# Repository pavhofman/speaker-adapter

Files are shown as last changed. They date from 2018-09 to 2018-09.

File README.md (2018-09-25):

# Adapter for Measuring Amplifier Speaker Outputs

## Overview
* Designed for soundcard balanced inputs
* Designed to fit [headless audio measurement workstation](https://github.com/pavhofman/measurement-station) but will work with any soundcard
* Can be switched to unbalanced mode (single-ended SE)
* Designed to fit FS Futro >=S450 case (inexpensive on ebay)

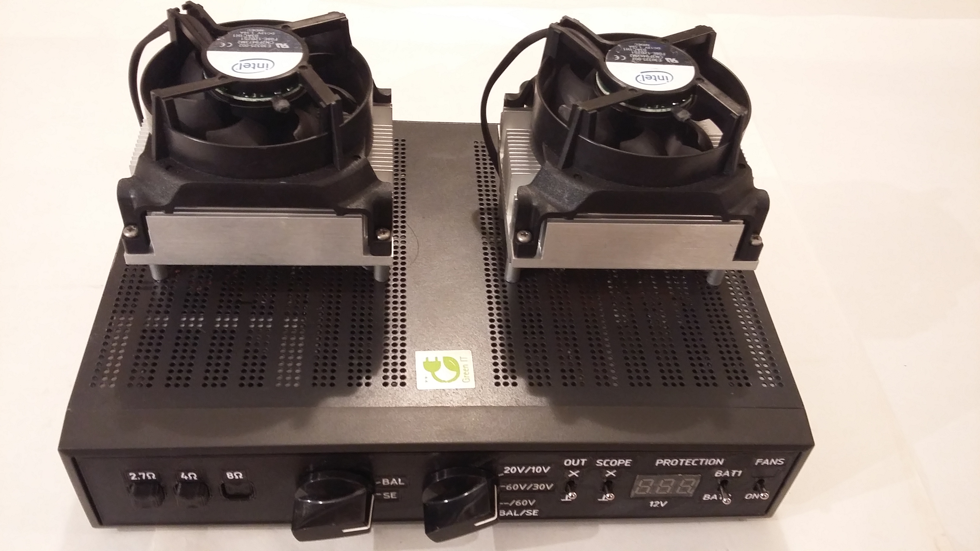
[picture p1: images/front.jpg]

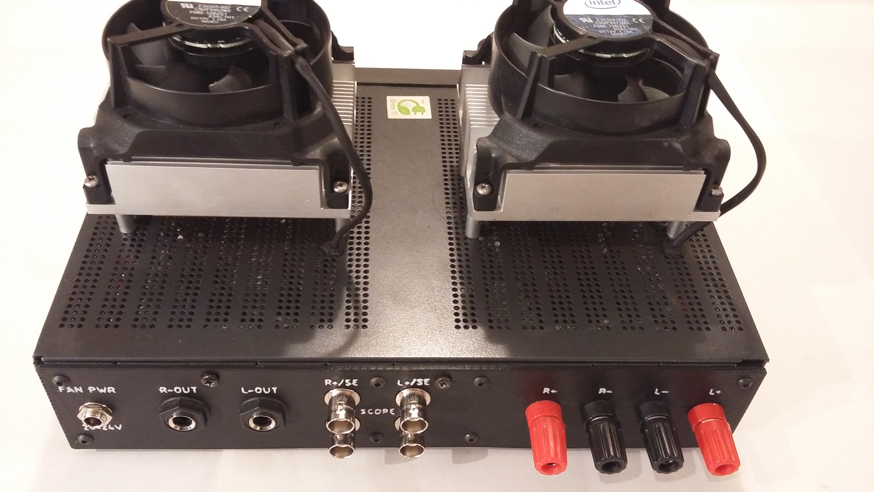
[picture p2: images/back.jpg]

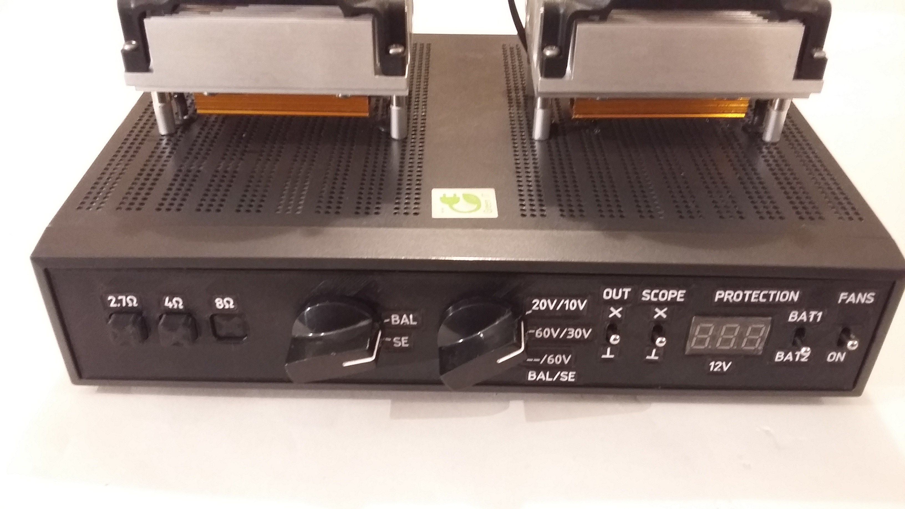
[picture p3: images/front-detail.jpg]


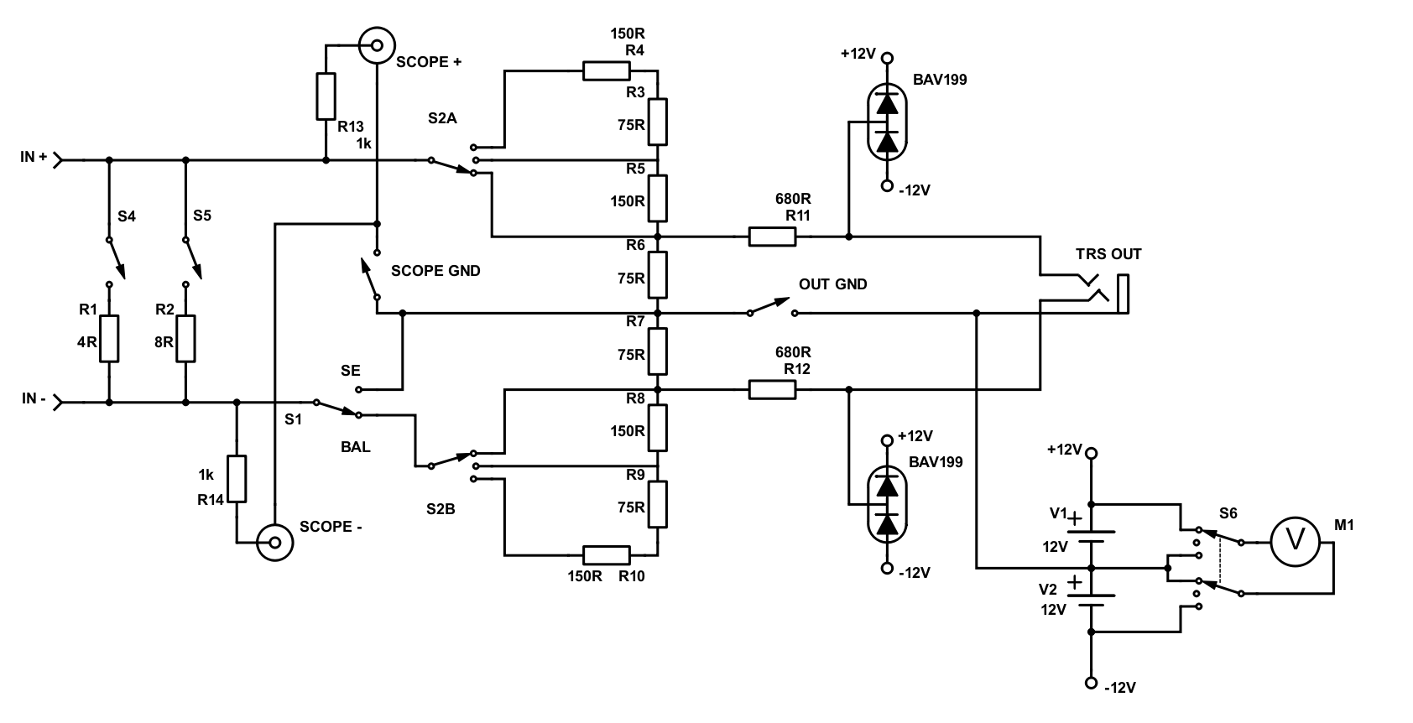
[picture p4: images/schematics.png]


## Speaker Load
* Load resistors - combination of 4R and 8R 100W resistors (ebay)
* Old/legacy CPU heatsinks with fans
* Fans powered by the measurement PC

## Ranges
* Ranges (voltages for ESI Juli):
  1. 1:1 (20Vmax balanced / 10Vmax SE) - divider 2 x 75R
  2. 1:3 (60Vmax balanced / 30Vmax SE) - divider 2 x (75R + 150R)
  3. 1:6 (120Vmax balanced - not supported/60Vmax SE) - divider 2 x (75R + 375R)
* Divider resistors 2W: 20V at (75R + 75R) -> 1.3W per each resistor
* Ground lift for balanced outputs

## Oscilloscope Output
* Each input line is connected to individual BNC connector for oscilloscope
* Ground lift for scope BNCs

## Soundcard Inputs Protection
* Serial output resistors 680R
* Soundcard hot/cold input protection by two internal voltage sources (2 x 2pcs A23 batteries)
* Protection diodes - dual low-leakage diodes BAV199
* Both sets of protection batteries checked by built-in voltmeter prior to measuring.

Scope screenshot of protection limiter kicking in for hot and cold lines of one output:



The adapter in action:

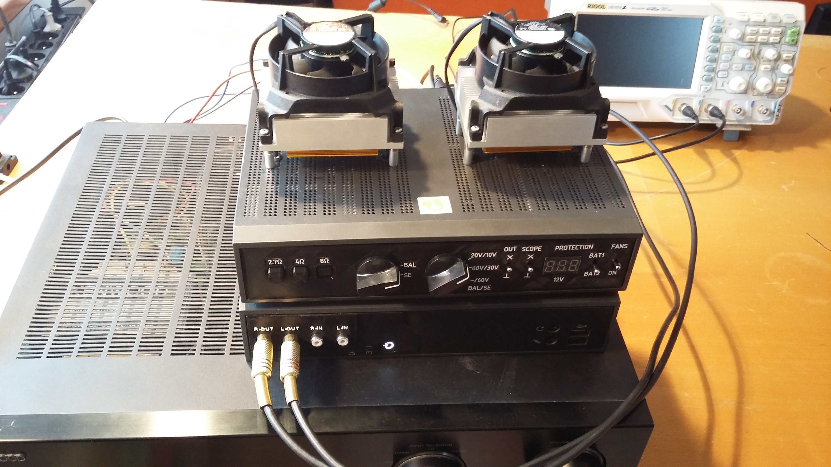
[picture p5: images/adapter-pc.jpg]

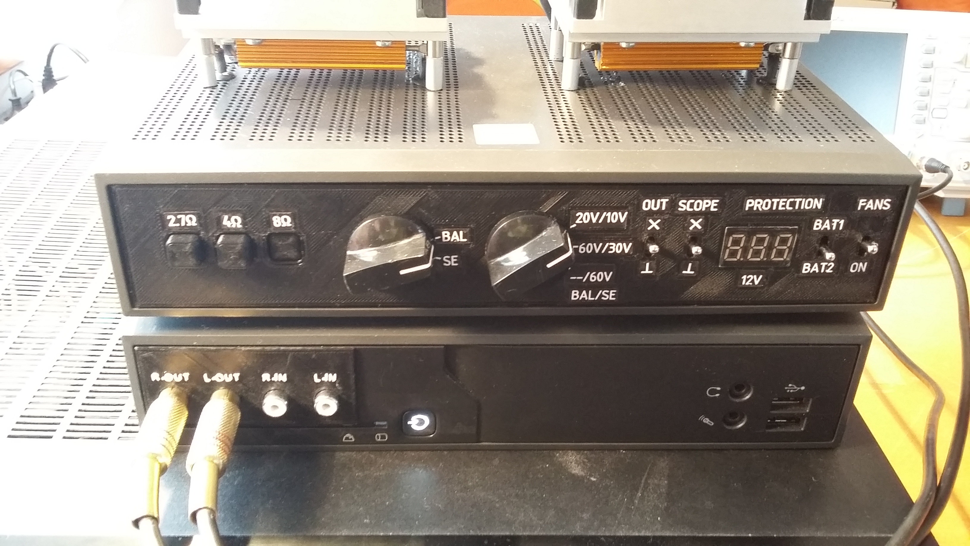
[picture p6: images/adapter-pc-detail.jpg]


## Construction
* Wired, no PCB
* SMD protection diodes soldered to small universal PCBs placed directly onto TRS sockets

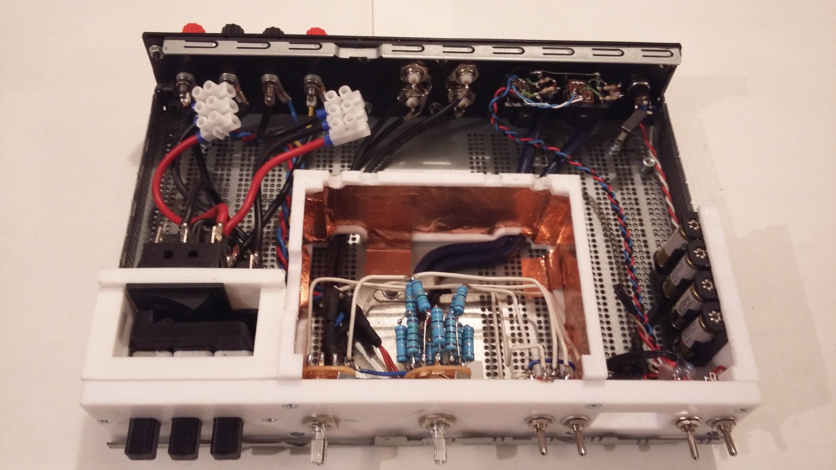
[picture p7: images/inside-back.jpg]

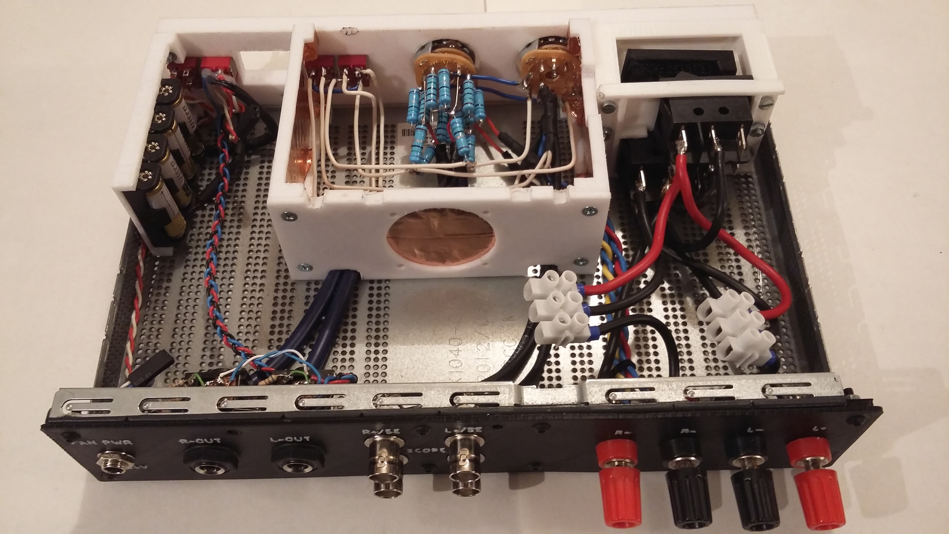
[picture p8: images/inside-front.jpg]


## Load-Resistors Switch
* 3D-printed, designed for regular 32mm rocker switches
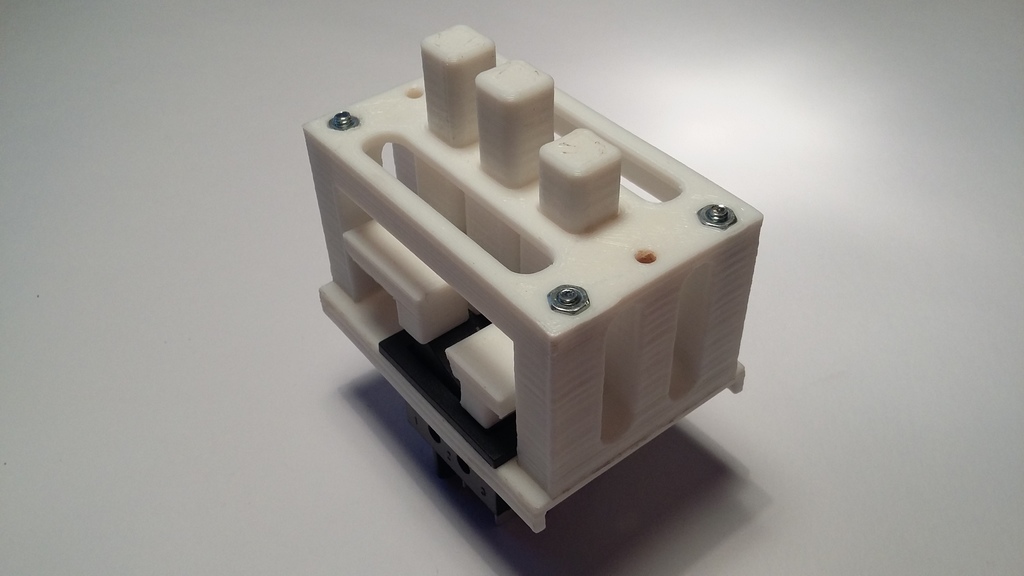
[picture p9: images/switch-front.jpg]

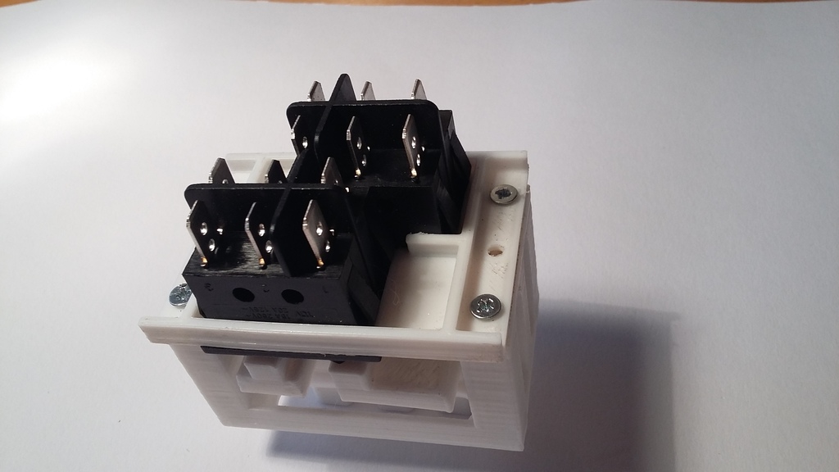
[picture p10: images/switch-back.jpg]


Position 2.7ohm - both resistors paralelly
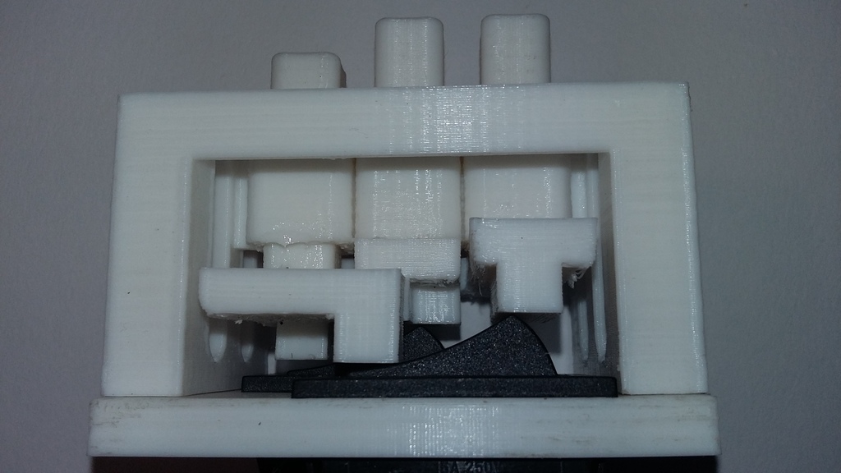
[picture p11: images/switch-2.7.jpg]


Position 4ohm
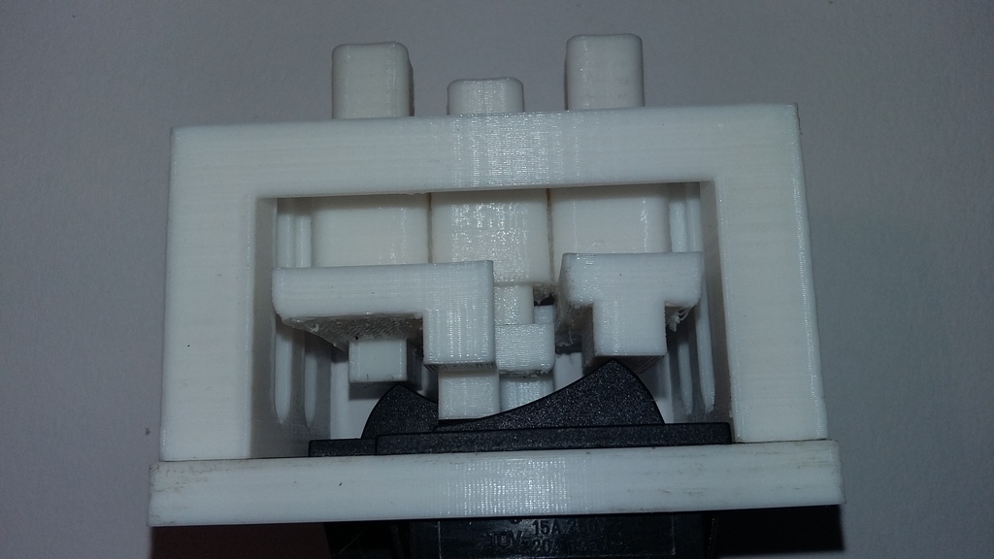
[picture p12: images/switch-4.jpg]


Position 8ohm
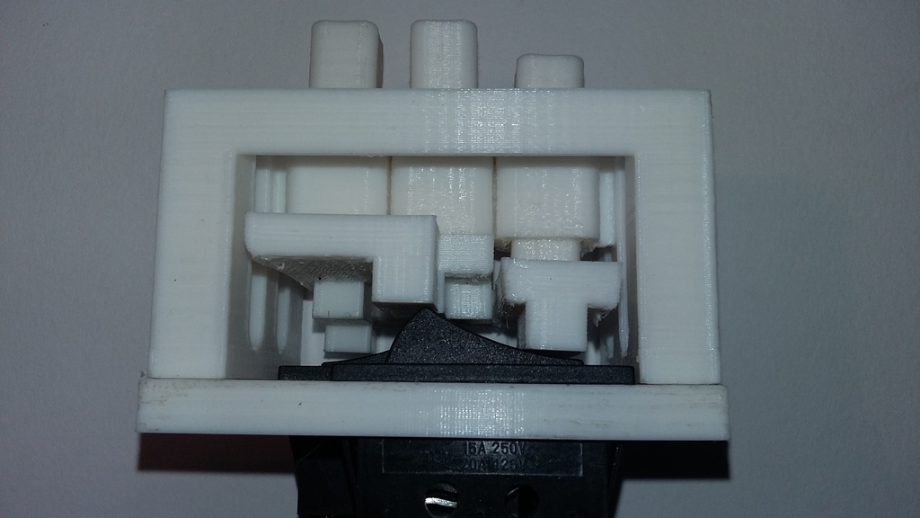
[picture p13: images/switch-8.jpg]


## Measurements
For comparison ESI Juli in virtual balanced inputs mode with L+R jacks shorted

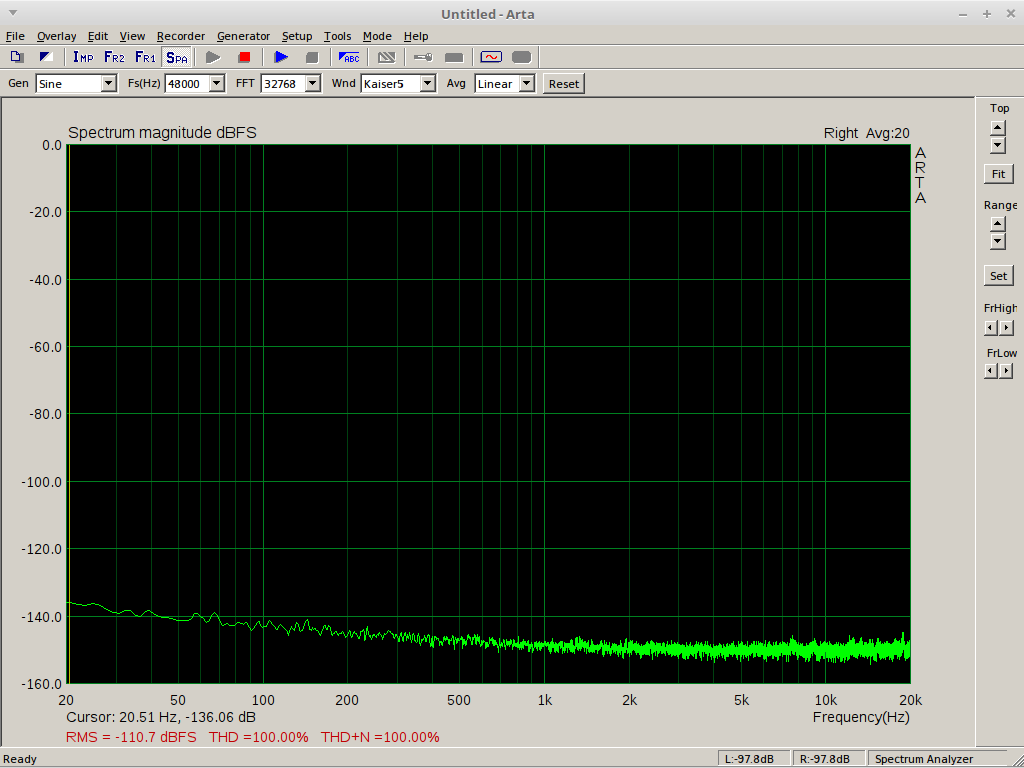
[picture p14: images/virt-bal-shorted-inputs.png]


Connected adapter, no input signal, virtual balanced inputs. Notice only minor increase in 50Hz noise, overall noise level unchanged.

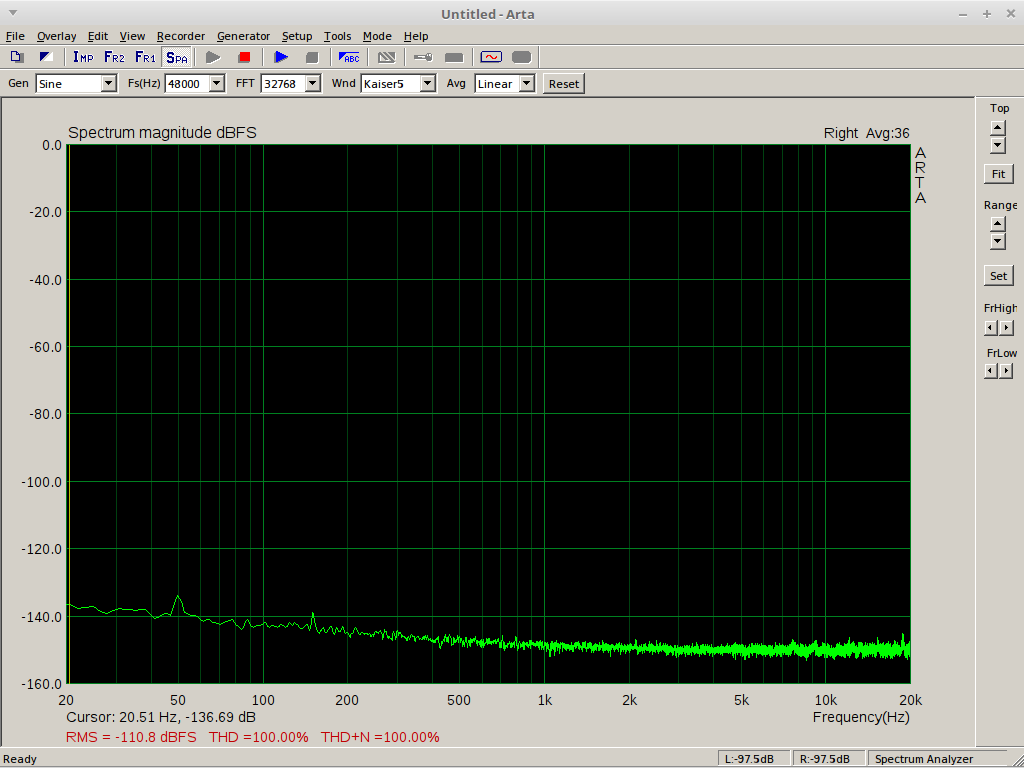
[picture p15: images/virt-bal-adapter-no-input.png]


Connected adapter, no input signal, native balanced inputs of ESI.
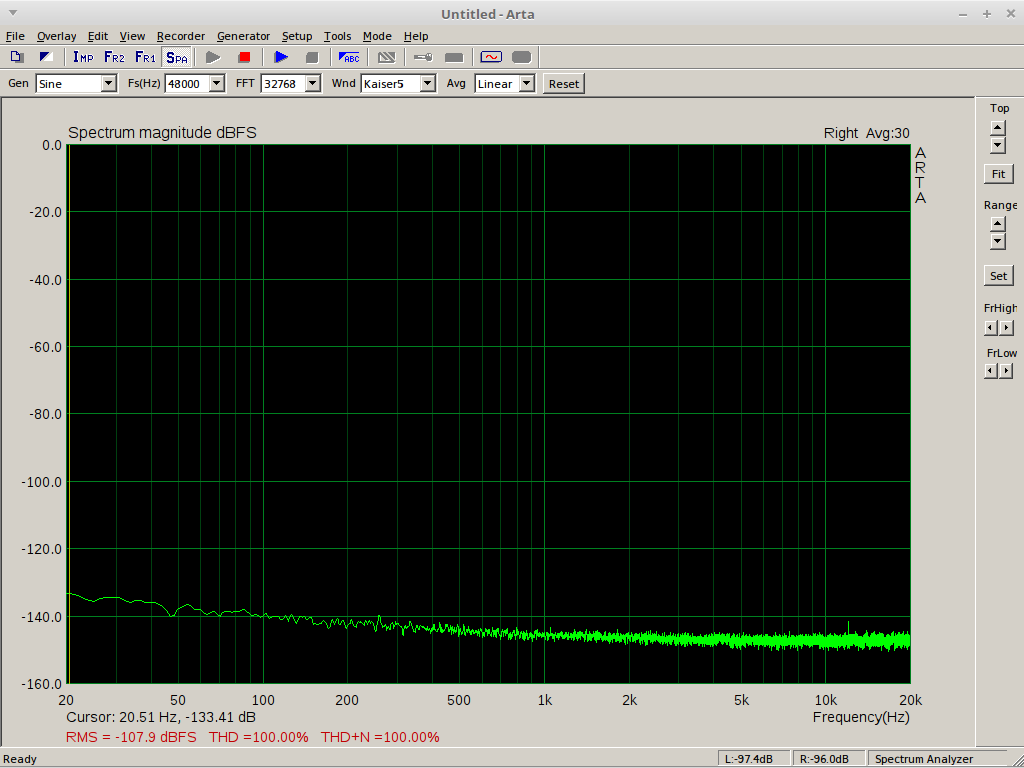
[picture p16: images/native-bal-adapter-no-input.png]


## Git repository
* All Fusion 360 backup files, STLs, front panel text image

## Conclusion
The measurements show the adapter does not bring any increase in noise of the measurement setup.

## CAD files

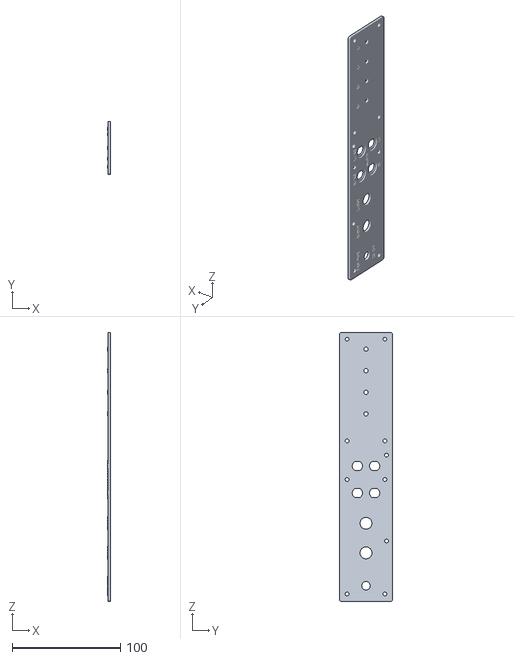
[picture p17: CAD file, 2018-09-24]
models/back_panels/Back_panel.stl
2.50 x 49.0 x 249.0

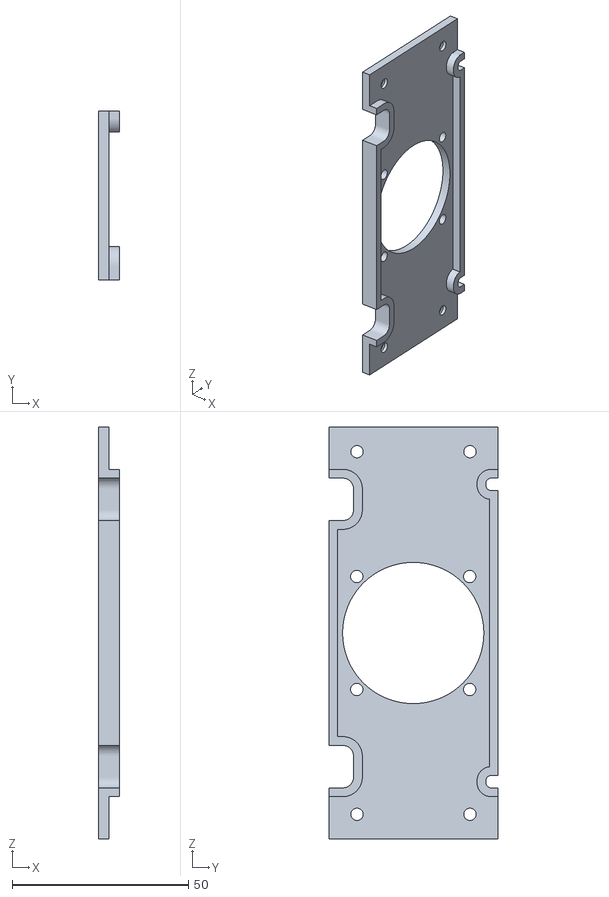
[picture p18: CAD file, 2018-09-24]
models/front_panels/BackShield.stl
6.00 x 48.0 x 116.8

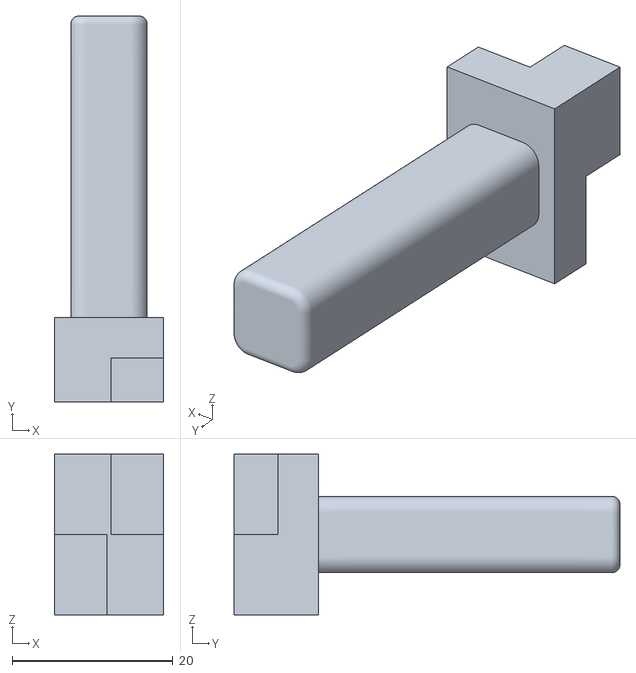
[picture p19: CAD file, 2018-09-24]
models/pushbuttons/CenterButton.stl
13.5 x 48.0 x 20.0

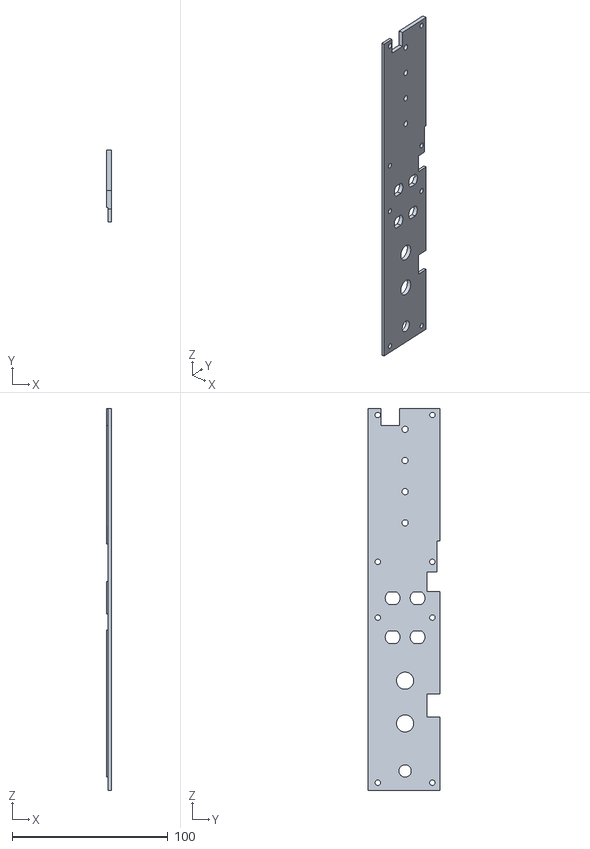
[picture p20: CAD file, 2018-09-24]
models/back_panels/Inside_Back_Panel.stl
3.00 x 46.4 x 245.0

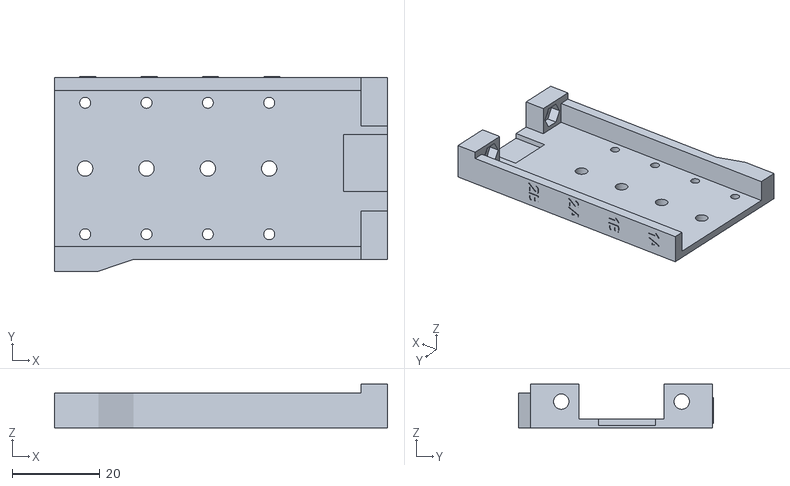
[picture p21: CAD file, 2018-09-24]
models/front_panels/BatteryPlate.stl
76.0 x 44.4 x 10.0

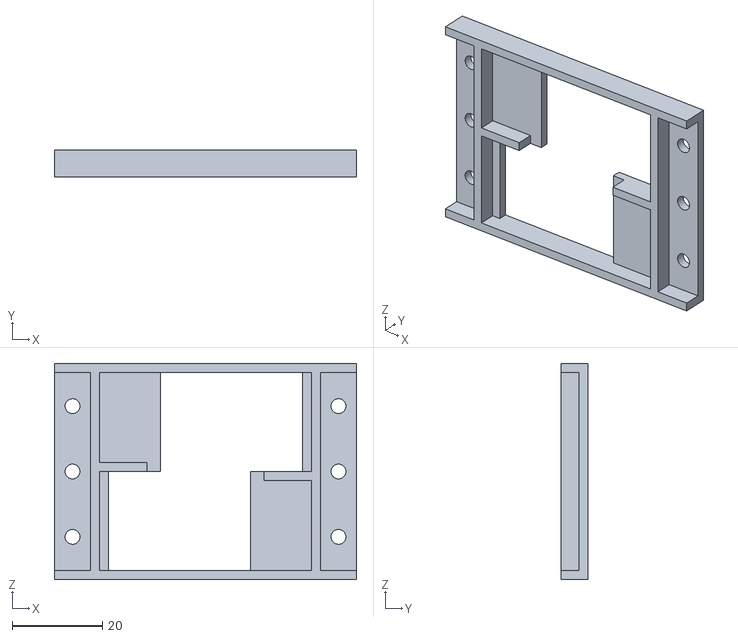
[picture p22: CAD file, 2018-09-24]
models/pushbuttons/SwitchHolderPlate.stl
67.0 x 6.00 x 48.0

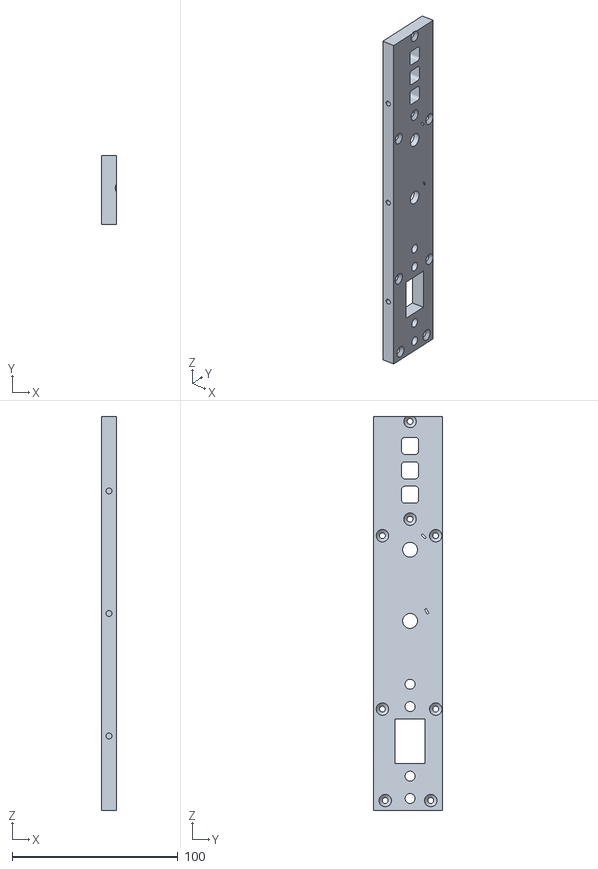
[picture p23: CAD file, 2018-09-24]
models/front_panels/HolderPanel.stl
9.00 x 41.5 x 238.0

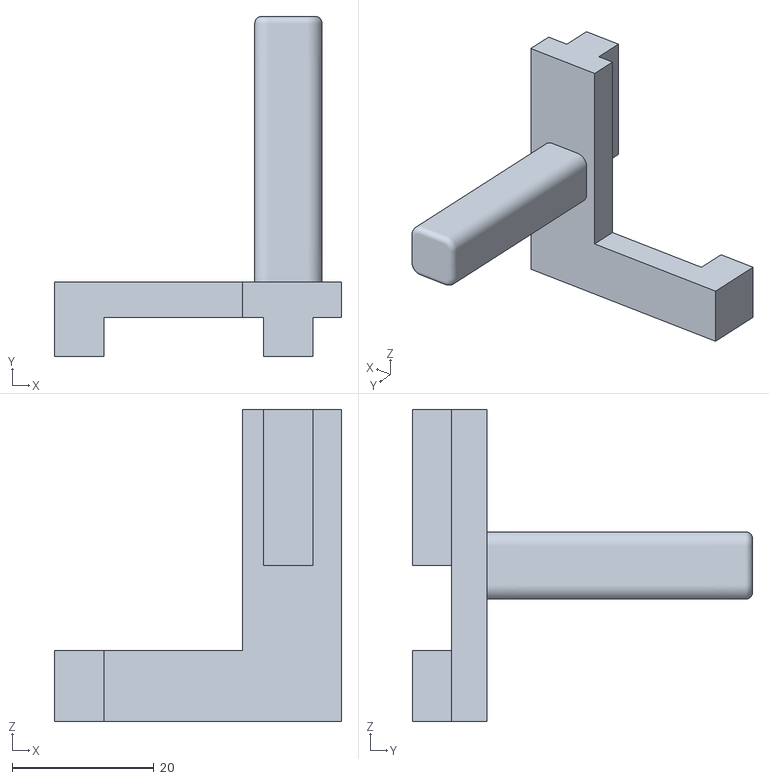
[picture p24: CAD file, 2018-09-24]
models/pushbuttons/RightButton.stl
40.5 x 48.0 x 44.0

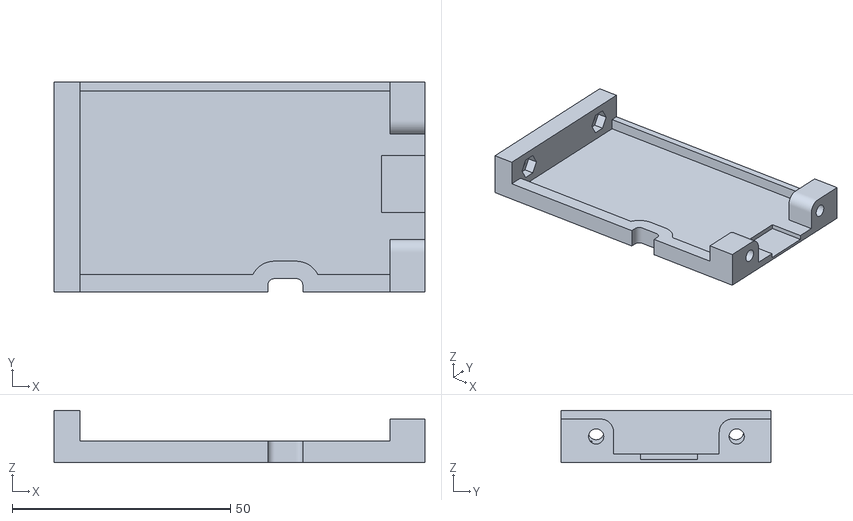
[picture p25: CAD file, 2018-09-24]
models/front_panels/RightShield.stl
85.0 x 48.0 x 12.0

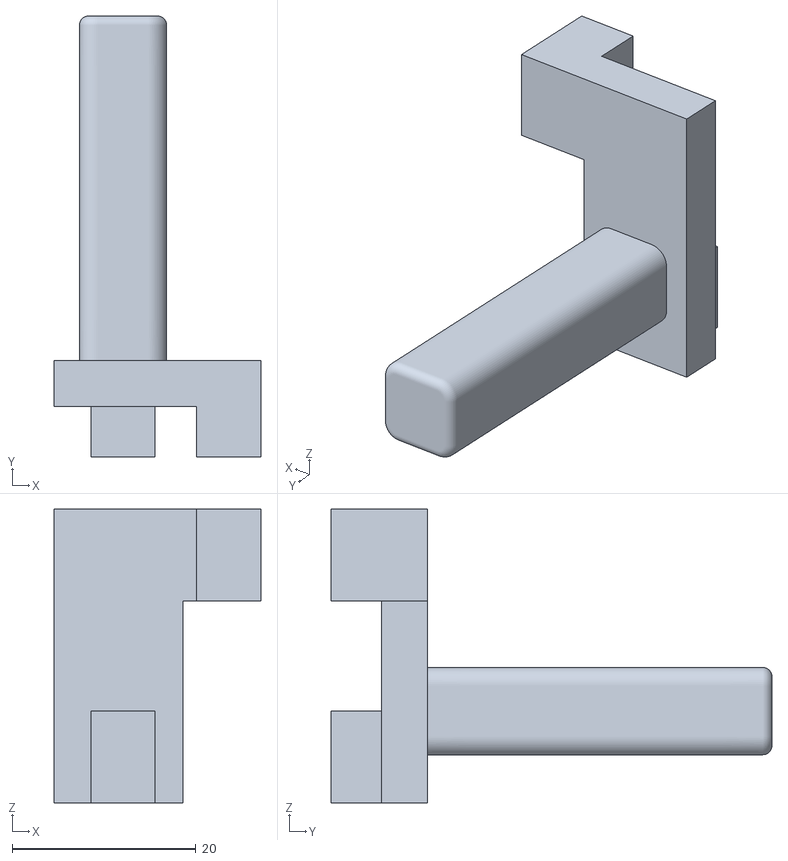
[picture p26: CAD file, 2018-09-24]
models/pushbuttons/LeftButton.stl
22.5 x 48.0 x 32.0

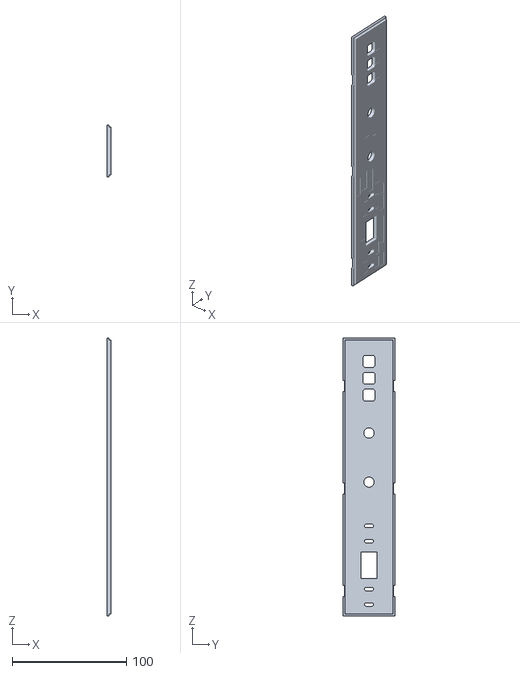
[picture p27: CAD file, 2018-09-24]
models/front_panels/FrontPanel_no_text.stl
3.30 x 45.5 x 243.5

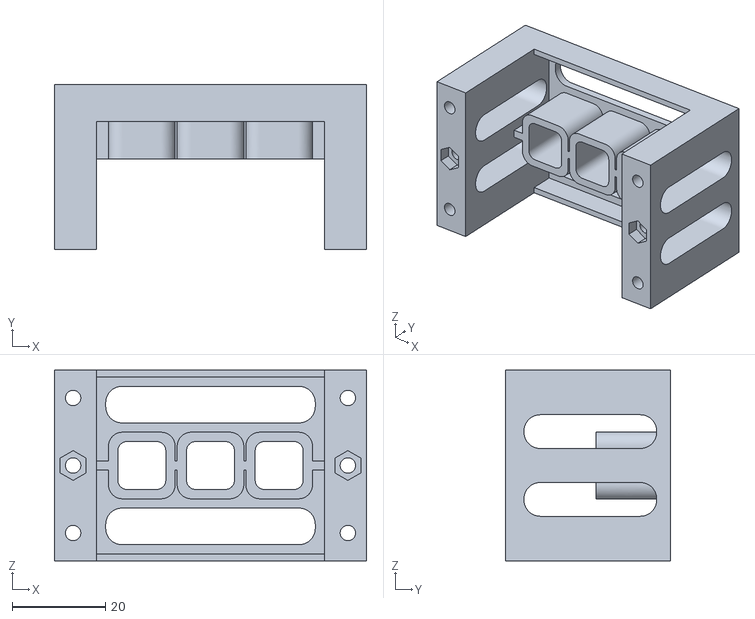
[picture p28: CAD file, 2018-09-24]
models/pushbuttons/CoverWithSleeves.stl
67.0 x 35.5 x 41.0

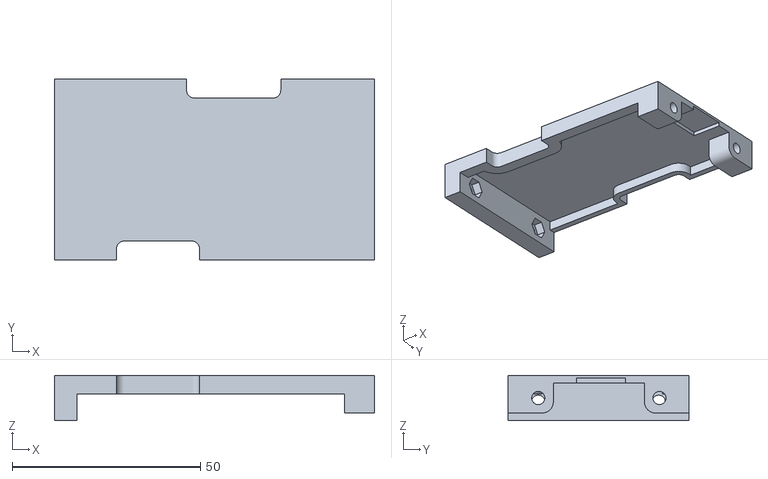
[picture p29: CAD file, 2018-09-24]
models/front_panels/LeftShield.stl
85.0 x 48.0 x 12.0

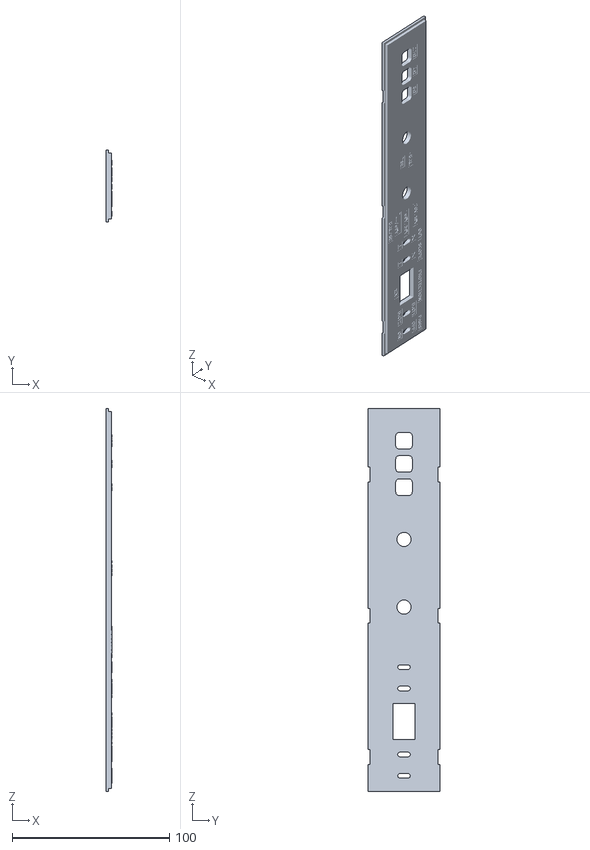
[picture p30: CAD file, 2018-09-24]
models/front_panels/FrontPanel_text.stl
3.50 x 45.5 x 243.5

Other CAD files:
models/back_panels/Back_panels.f3d

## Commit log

2018-09-24 Schematics, models
    [BackShield.stl, Back_panel.stl, Back_panels.f3d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]
2018-09-24 Fixed schematics
